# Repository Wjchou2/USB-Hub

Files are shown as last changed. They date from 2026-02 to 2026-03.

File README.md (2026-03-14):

# Endless' USB HUB

A compact custom USB 2.0 hub PCB based on the USB2514B controller. It features two USB-A ports and a 4-pin header breakout for easy integration with embedded systems or custom hardware projects.
Simply use a USB-C to C cable to plug the hub into your computer, and check that the LED indicator is on. Then connect any USB-A devices and they will show up on your computer.
I made this project because I have a Mac and never seem to have enough adapters, I also find that I use 4 pin headers often when tinkering with microcontrollers, so I added an easy access 4 pin header integrated into the hub. 

<br>
<br>
No firmware needed!

Screenshot 2026-01-31 at 4 56 15 PM
Screenshot 2026-01-31 at 4 55 53 PM
Screenshot 2026-01-31 at 11 14 54 PM
Screenshot 2026-01-31 at 11 34 22 PM

BOM:
| Designator  | Footprint | Quantity | Designation | Link | Cost | Total Cost |
|---|---|---|---|---|---|---|
| U2 | SOT-223 | 1 | AMS1117-3.3 | https://www.lcsc.com/product-detail/C6186.html?s_z=n_AMS1117-3.3 | 0.1876 | 0.1876 |
| R3 | R_0603_1608Metric_Pad0.98x0.95mm_HandSolder | 1 | 12k | https://www.lcsc.com/product-detail/C2906989.html?s_z=n_12k%25201%2525%25200603 | 0.001  | 0.001 |
| R7,R6,R8,R9 | R_0603_1608Metric_Pad0.98x0.95mm_HandSolder | 4 | 10k | https://www.lcsc.com/product-detail/C98220.html?s_z=n_10k%25201%2525%25200603 | 0.0013 | 0.0052 |
| J2,J3 | USB_A_Receptacle_GCT_USB1046 | 2 | USB_A | https://www.lcsc.com/product-detail/C6307429.html?s_z=n_USB1046 | 1.1405 | 2.281 |
| C2,C1,C7 | C_0805_2012Metric_Pad1.18x1.45mm_HandSolder | 3 | 0.1µ | https://www.lcsc.com/product-detail/C53084456.html?s_z=n_100%2520nF%252050V%2520X7R%25200805 | 0.0018 | 0.0054 |
| C4,C3 | C_0603_1608Metric_Pad1.08x0.95mm_HandSolder | 2 | 22 pF | https://www.lcsc.com/product-detail/C695385.html?s_z=n_22%2520pF%2520NPO%25200603 | 0.051  | 0.102 |
| Y1 | Crystal_SMD_3225-4Pin_3.2x2.5mm | 1 | 12.000 MHz | https://www.lcsc.com/product-detail/C1647.html?s_z=n_18%2520pF%2520crysta | 0.3272 | 0.3272 |
| J5 | PinHeader_1x04_P2.54mm_Vertical | 1 | Conn_01x04_Socket | https://www.lcsc.com/product-detail/C52016392.html?s_z=n_Pin%2520Header%25201x04%25202.54mm | 0.0171 | 0.0171 |
| R2,R1 | R_0603_1608Metric_Pad0.98x0.95mm_HandSolder | 2 | 5.1k | https://www.lcsc.com/search?q=5.1k%25201%2525%25200603&s_z=n_5.1k%25201%2525%25200603 | 0.0012 | 0.0024 |
| R4,R5 | R_0603_1608Metric_Pad0.98x0.95mm_HandSolder | 2 | 100k | https://www.lcsc.com/product-detail/C14675.html?s_z=n_100k%25201%2525%25200603 | 0.0013 | 0.0026 |
| C6,C5 | C_1206_3216Metric_Pad1.33x1.80mm_HandSolder | 2 | 10 µF | https://www.lcsc.com/product-detail/C342827.html?s_z=n_10%2520uF%252016V%2520X7R%25201206 | 0.0897 | 0.1794 |
| F1 | Fuse_1812_4532Metric_Pad1.30x3.40mm_HandSolder | 1 | 0.5A | https://www.lcsc.com/product-detail/C7542969.html?s_z=n_PTC%2520fuse%25200.5A%25201812 | 0.0403 | 0.0403 |
| J1 | USB_C_Receptacle_GCT_USB4105-xx-A_16P_TopMnt_Horizontal | 1 | USB_C_Receptacle_USB2.0_16P | https://www.lcsc.com/product-detail/C2988369.html?s_z=n_USB%2520C%2520receptacle%252016P%2520top%2520mount | 0.0829 | 0.0829 |
| U1 | QFN-36-1EP_6x6mm_P0.5mm_EP3.7x3.7mm | 1 | USB2514B_Bi | https://www.lcsc.com/product-detail/C220807.html?s_z=n_USB2514B%2520USB%2520hub%25204-port%2520Octopart | 2.7952 | 2.7952 |
| R10 | R_0603_1608Metric_Pad0.98x0.95mm_HandSolder | 1 | 1.5kΩ | https://www.lcsc.com/product-detail/C22843.html?s_z=n_1.5k%25201%2525%25200603 | 0.0012 | 0.0012 |
| D1 | LED_0201_0603Metric_Pad0.64x0.40mm_HandSolder | 1 | LED | https://www.lcsc.com/search?q=LED%25200603%2520Green&s_z=n_LED%25200603%2520Green | 0.0667 | 0.0667 |
| | | | | | | 6.0972 |

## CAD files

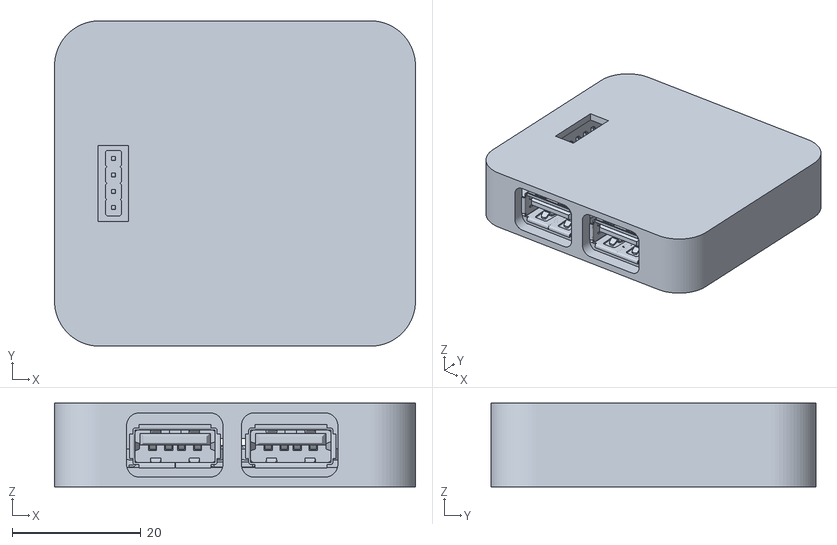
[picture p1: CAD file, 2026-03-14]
CAD/USBHubWithComponents.stl
56.1 x 50.6 x 13.0

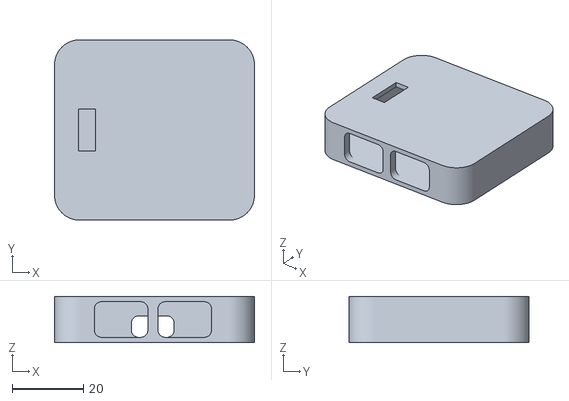
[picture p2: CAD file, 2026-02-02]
CAD/USBHub CASE.stl
56.1 x 50.6 x 13.0

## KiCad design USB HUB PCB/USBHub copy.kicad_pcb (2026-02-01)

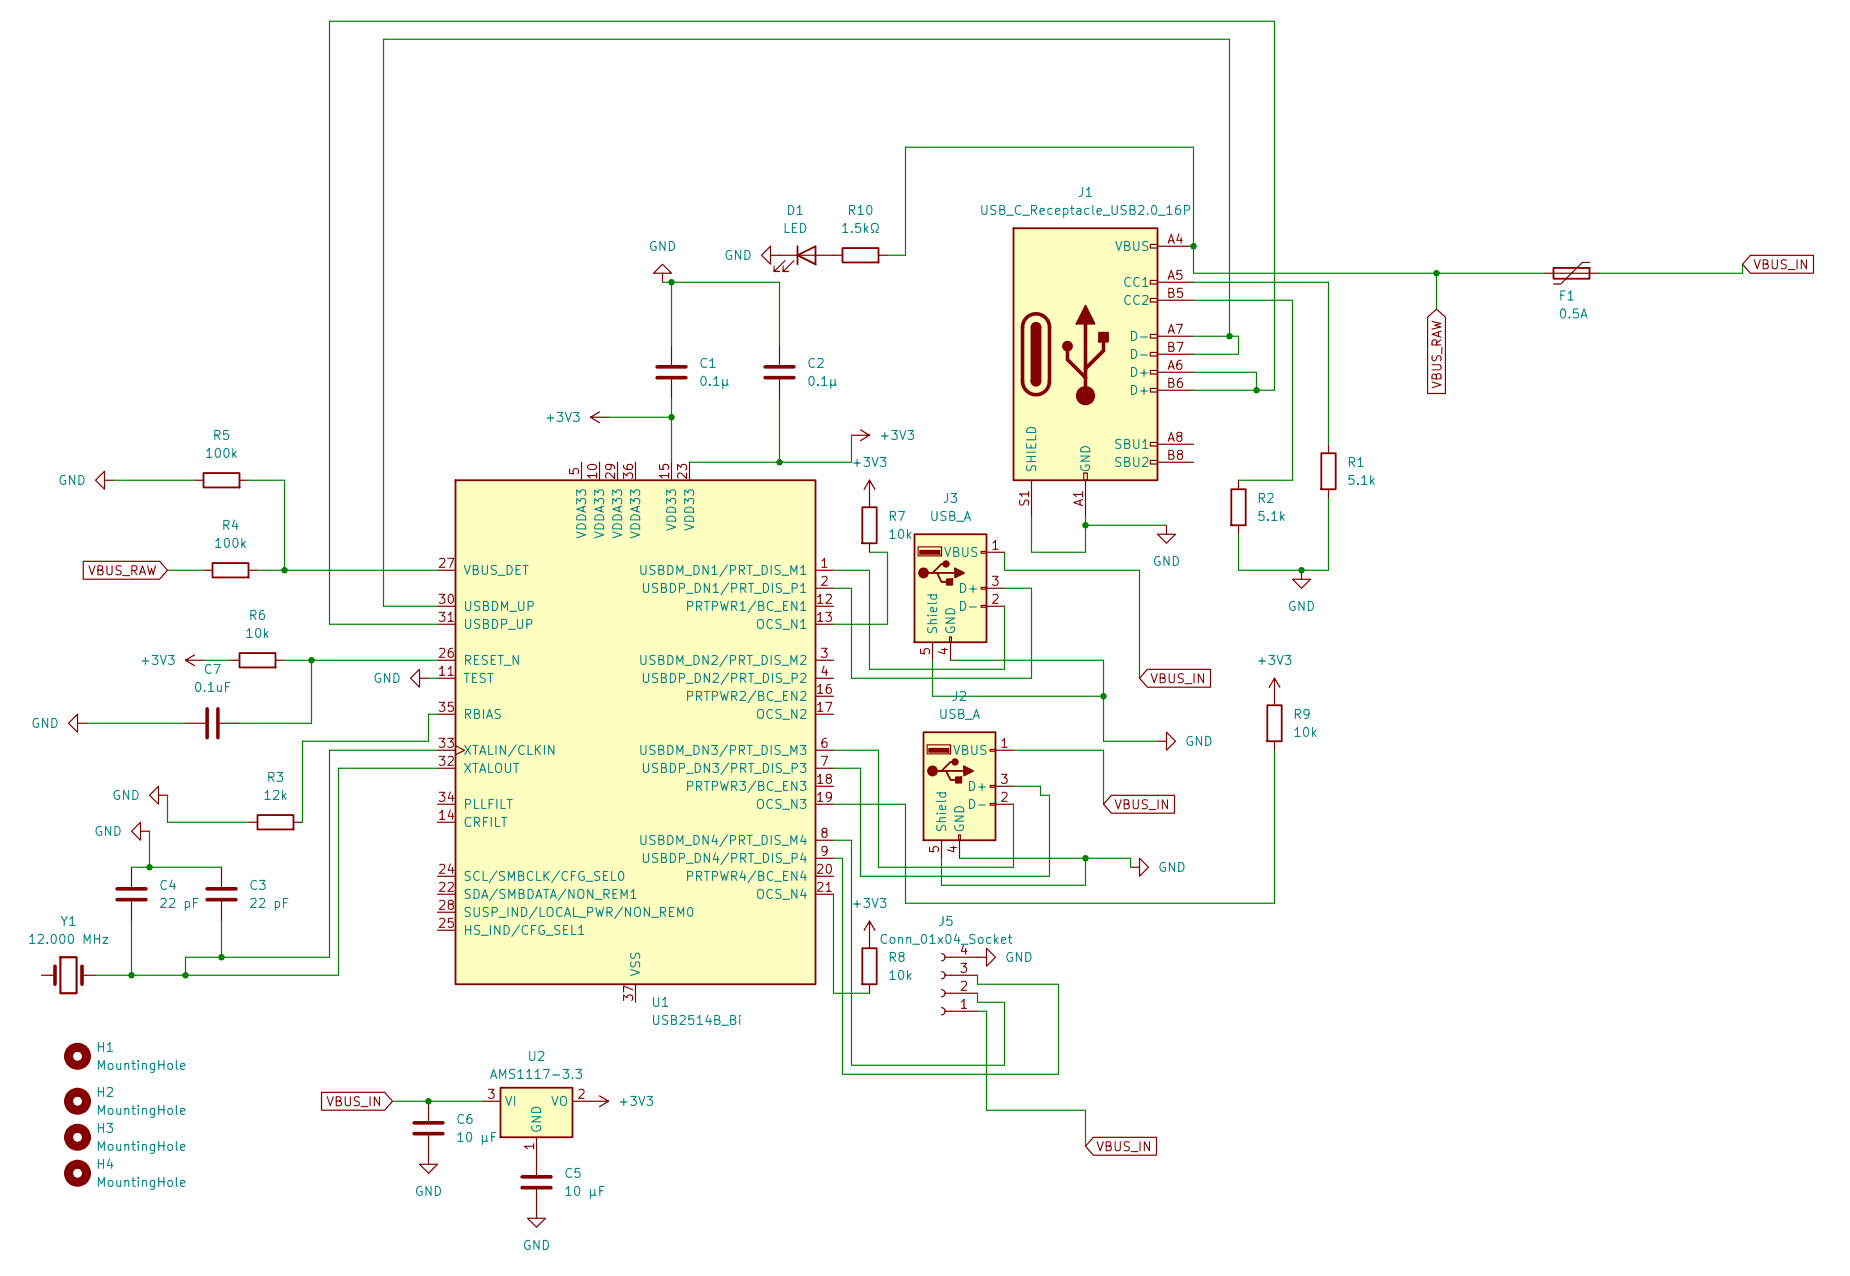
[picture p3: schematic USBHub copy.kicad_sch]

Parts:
C1, C2: 0.1µ; C_0805_2012Metric_Pad1.18x1.45mm_HandSolder
C3, C4: 22 pF; C_0603_1608Metric_Pad1.08x0.95mm_HandSolder
C5, C6: 10 µF; C_1206_3216Metric_Pad1.33x1.80mm_HandSolder
C7: 0.1uF; C_0805_2012Metric_Pad1.18x1.45mm_HandSolder
D1: LED; LED_0201_0603Metric_Pad0.64x0.40mm_HandSolder
F1: 0.5A; Fuse_1812_4532Metric_Pad1.30x3.40mm_HandSolder
H1, H2, H3, H4: MountingHole; MountingHole_2.2mm_M2
J1: USB_C_Receptacle_USB2.0_16P; USB_C_Receptacle_GCT_USB4105-xx-A_16P_TopMnt_Horizontal
J2, J3: USB_A; USB_A_Receptacle_GCT_USB1046
J5: Conn_01x04_Socket; PinHeader_1x04_P2.54mm_Vertical
R1, R2: 5.1k; R_0603_1608Metric_Pad0.98x0.95mm_HandSolder
R3: 12k; R_0603_1608Metric_Pad0.98x0.95mm_HandSolder
R4, R5: 100k; R_0603_1608Metric_Pad0.98x0.95mm_HandSolder
R6, R7, R8, R9: 10k; R_0603_1608Metric_Pad0.98x0.95mm_HandSolder
R10: 1.5kΩ; R_0603_1608Metric_Pad0.98x0.95mm_HandSolder
U1: USB2514B_Bi; QFN-36-1EP_6x6mm_P0.5mm_EP3.7x3.7mm
U2: AMS1117-3.3; SOT-223
Y1: 12.000 MHz; Crystal_SMD_3225-4Pin_3.2x2.5mm

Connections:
+3V3: C1.2, C2.2, R6.1, R7.1, R8.1, R9.1, U1.15 (VDD33), U1.23 (VDD33), U2.2 (VO)
GND: C1.1, C2.1, C3.1, C4.1, C5.2, C6.2, C7.1, D1.1 (K), J1.A1 (GND), J1.A12 (GND), J1.B1 (GND), J1.B12 (GND), J1.S1 (SHIELD), J2.4 (GND), J2.5 (Shield), J3.4 (GND), J3.5 (Shield), J5.4, R1.2, R2.2, R3.1, R5.1, U1.11 (TEST)
unnamed: D1.2 (A), R10.1
unnamed: J1.A5 (CC1), R1.1
unnamed: J1.B5 (CC2), R2.1
unnamed: J2.3 (D+), U1.7 (USBDP_DN3/PRT_DIS_P3)
unnamed: J2.2 (D-), U1.6 (USBDM_DN3/PRT_DIS_M3)
unnamed: J3.3 (D+), U1.2 (USBDP_DN1/PRT_DIS_P1)
unnamed: J3.2 (D-), U1.1 (USBDM_DN1/PRT_DIS_M1)
unnamed: J5.2, U1.8 (USBDM_DN4/PRT_DIS_M4)
unnamed: J5.3, U1.9 (USBDP_DN4/PRT_DIS_P4)
unnamed: R7.2, U1.13 (OCS_N1)
unnamed: R9.2, U1.19 (OCS_N3)
unnamed: R8.2, U1.21 (OCS_N4)
unnamed: R3.2, U1.35 (RBIAS)
unnamed: C7.2, R6.2, U1.26 (RESET_N)
unnamed: J1.A7 (D-), J1.B7 (D-), U1.30 (USBDM_UP)
unnamed: J1.A6 (D+), J1.B6 (D+), U1.31 (USBDP_UP)
unnamed: R4.2, R5.2, U1.27 (VBUS_DET)
unnamed: C3.2, C4.2, U1.32 (XTALOUT), U1.33 (XTALIN/CLKIN), Y1.2
unnamed: C5.1, U2.1 (GND)
VBUS_IN: C6.1, F1.1, J2.1 (VBUS), J3.1 (VBUS), J5.1, U2.3 (VI)
VBUS_RAW: F1.2, J1.A4 (VBUS), J1.A9 (VBUS), J1.B4 (VBUS), J1.B9 (VBUS), R4.1, R10.2

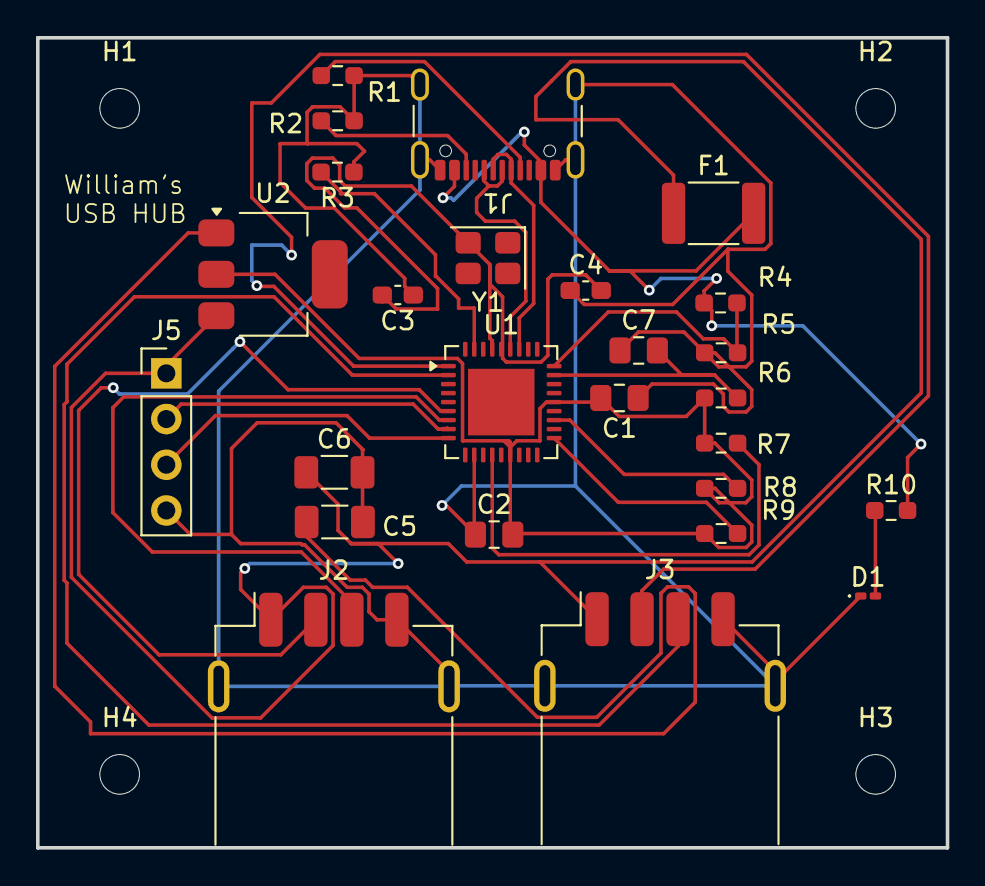
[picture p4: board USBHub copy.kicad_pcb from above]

Board: 2 copper layers, 50.5 x 45.0 mm, 30 parts (0 on the bottom side), 23 nets.
